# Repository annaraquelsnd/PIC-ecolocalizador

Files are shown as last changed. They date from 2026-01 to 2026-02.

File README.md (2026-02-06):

# Ecolocalizador Tátil para Bicicletas Tandem

Dispositivo de assistência baseado em **feedback tátil** para aumentar a **segurança**, a **confiança** e a **autonomia** de pessoas com deficiência visual na condução de bicicletas tandem.

> Projeto desenvolvido na disciplina **Projeto Integrado de Computação I** para a **Mostra de Computação da UFES** com o professor Jadir E. S. Lucas.

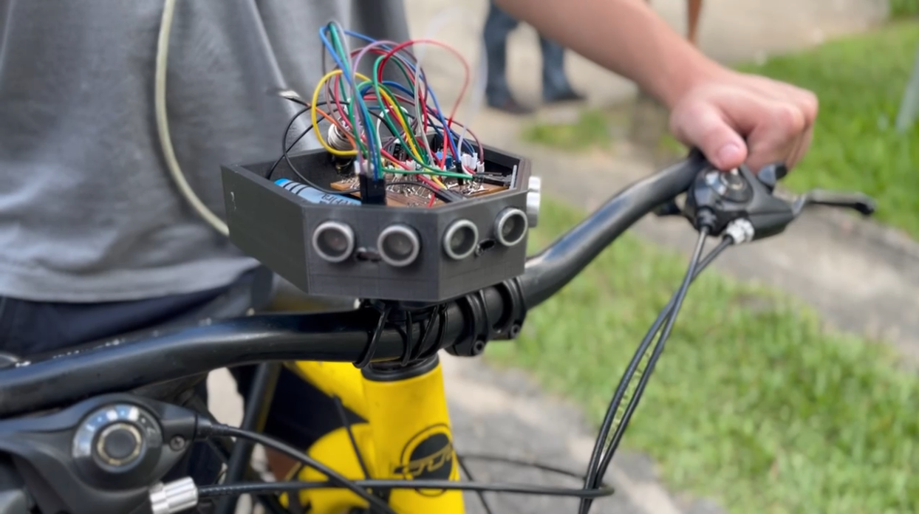
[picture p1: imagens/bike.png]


---

## 📌 Contexto e Motivação

A percepção do ambiente não depende exclusivamente da visão. Casos como o de **Ben Underwood** demonstram que outros sentidos podem ser explorados para navegação espacial.

<p align="center">
  <a href="https://www.youtube.com/watch?v=pt5yYK_4Rjo">
    Ben Underwood
  </a>
</p>
<p align="center">
▶️ Clique na imagem para assistir no YouTube
</p>

Inspirados por essa ideia e por iniciativas como o projeto **Pedal Inclusão**, que utiliza bicicletas tandem para permitir que pessoas com deficiência visual pratiquem o ciclismo, tivemos contato direto com os desafios e possibilidades dessa experiência.

Durante um desses eventos, observamos um participante com deficiência visual conduzir a bicicleta apenas com orientações verbais de sua dupla. A experiência evidenciou o potencial da atividade, mas também deixou claro que a condução exige um alto nível de confiança.

A partir dessa vivência, pensamos em uma **solução técnica** que aumentasse a sensação de segurança e encorajasse mais pessoas com deficiência visual a assumir a condução da bicicleta, tornando a atividade mais inclusiva.

---

## 🎯 Objetivos do Projeto

- Encorajar o ciclista com deficiência visual a conduzir a bicicleta 
- Reduzir a dependência exclusiva de comandos verbais
- Fornecer percepção espacial por meio de feedback tátil
- Tornar a condução mais acessível e o esporte mais inclusivo

---

## 🧠 Visão Geral do Sistema

O sistema é composto por dois módulos principais:

- **Central no guidão da bicicleta**, responsável pela detecção de obstáculos
- **Colete tátil**, responsável por transmitir informações espaciais ao ciclista por meio da vibração

A comunicação entre esses módulos permite que a presença e a direção de obstáculos sejam percebidas.

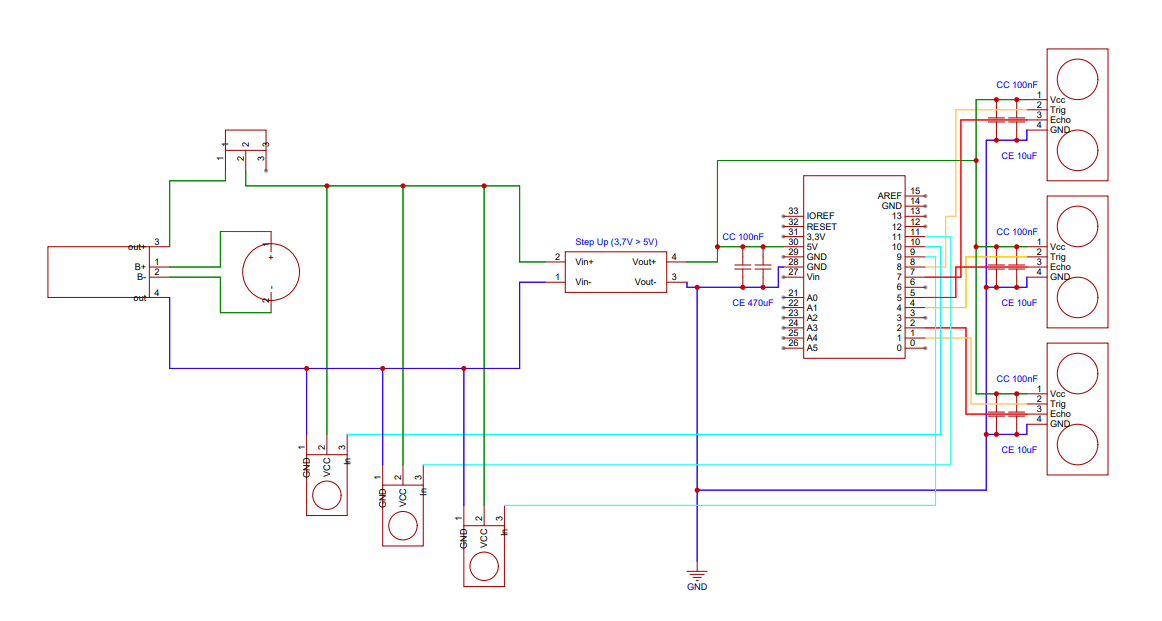
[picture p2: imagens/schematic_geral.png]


---

## 🏗️ Arquitetura do Sistema

### 🔹 Central (Guidão)

A central é responsável pela leitura do ambiente à frente da bicicleta.

#### Componentes principais:
###### Arduino UNO
- Contém o algoritmo que converte a distância medida em intensidade de vibração. Quanto mais perto, maior é a intensidade da vibração.
```c++
...
// Dispara o pulso ultrassônico
digitalWrite(trigPin, LOW);
delayMicroseconds(2);
digitalWrite(trigPin, HIGH);
delayMicroseconds(10);
digitalWrite(trigPin, LOW);

// Lê o retorno
long duracao = pulseIn(echoPin, HIGH);
int distancia = duracao * 0.034 / 2;

// Calcula a Intensidade 
int pwm = 0;

if (distancia == 0 || distancia > DISTANCIA_MAX) {
  pwm = 0; // Desligado
} 
else if (distancia < DISTANCIA_MIN) {
  pwm = 255; // Vibração Máxima
} 
else {
  // Quanto mais perto, mais forte
  pwm = map(distancia, DISTANCIA_MIN, DISTANCIA_MAX, 255, 0);
}

// Aciona o Motor
analogWrite(motorPin, pwm);
...
```

###### 3 sensores ultrassônicos (HC-SR04)
- Dispostos em três faces frontais do chassi angulados em **45º** entre si
Tem um alcance de até 3 metros
- Estão posicionados no guidão, cobrindo aproximadamente **120°** à frente da bicicleta.
<table>
  <tr>
    <td>
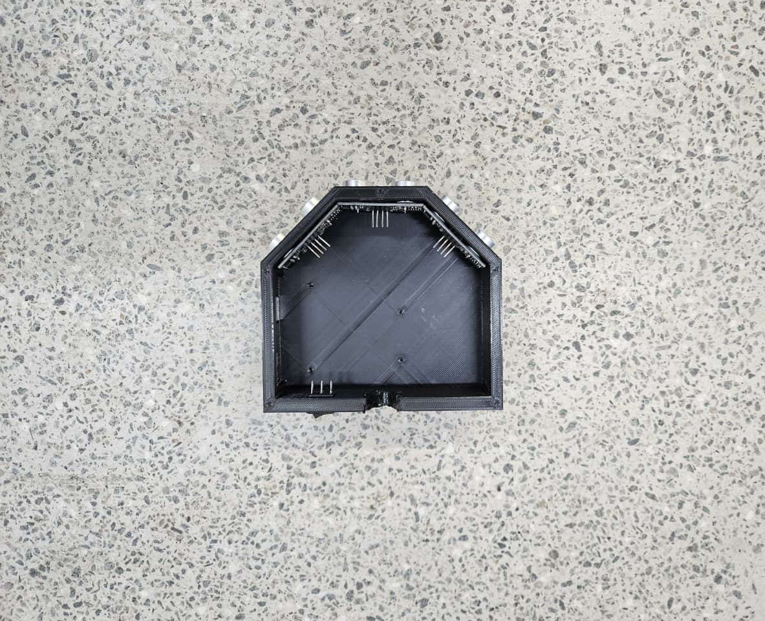
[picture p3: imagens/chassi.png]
      
    </td>
    <td>
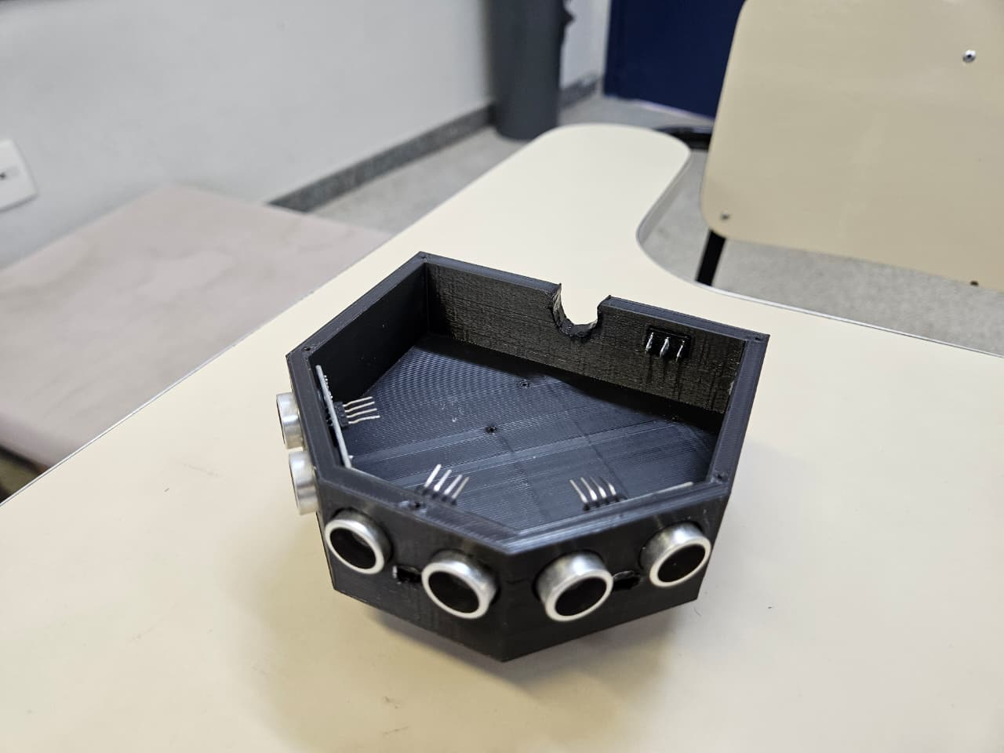
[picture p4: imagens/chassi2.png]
      
  </tr>
</table>

###### Alimentação dedicada
- Bateria 3.7V 18650 recarregável
- Módulo de carregamento TP4056

Esses componentes são centralizados em uma placa PCB:
<table>
  <tr>
    <td>
      
    </td>
    <td>
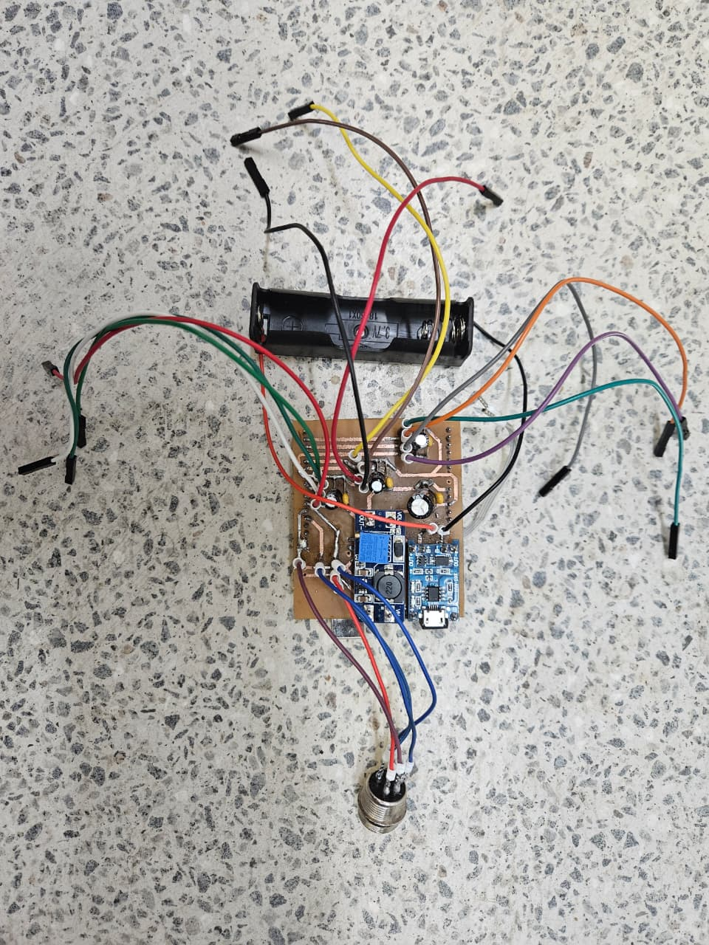
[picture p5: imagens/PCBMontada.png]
      
  </tr>
</table>

---
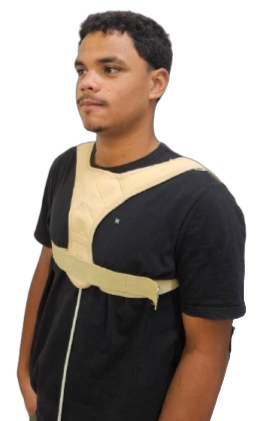
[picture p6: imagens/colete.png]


### 🔹 Colete Tátil

O colete é responsável por fornecer o feedback sensorial ao ciclista.

##### Componentes principais:
- 3 motores de vibração
- PCB
- Estrutura vestível (colete)

##### Os motores estão posicionados:
- Um no centro do peito
- Um em cada ombro

---

## 🔄 Mapeamento Sensor → Vibração

A informação captada pelos sensores é convertida em padrões de vibração, indicando a direção do obstáculo.

| Sensor | Posição no guidão | Motor ativado | Indicação |
|---|---|---|---|
| Sensor esquerdo | Esquerda | Ombro esquerdo | Obstáculo à esquerda |
| Sensor central | Centro | Peito | Obstáculo frontal |
| Sensor direito | Direita | Ombro direito | Obstáculo à direita |

---

## 🧩 Componentes Utilizados

| Componente | Quantidade | Função |
|---|---|---|
| Arduino | 1 | Processamento dos dados |
| Sensor ultrassônico HC-SR04| 3 | Detecção de obstáculos |
| Motor de vibração | 3 | Feedback tátil |
| PCB personalizada | 2 | Integração do sistema |
| Estrutura do colete | 1 | Fixação dos motores |
| Cabos e conectores | Diversos | Interligação |

---

## 🛠️ Processo de Desenvolvimento

#### O desenvolvimento do projeto passou pelas seguintes etapas:

- Levantamento do problema a partir de vivência prática
- Idealização do aparelho
- Levantamento de componentes necessários
- Prototipação inicial
- Projeto e confecção das PCBs
- Modelagem e impressão 3D
- Montagem dos módulos
- Testes funcionais do sistema

<table>
  <tr>
    <td>
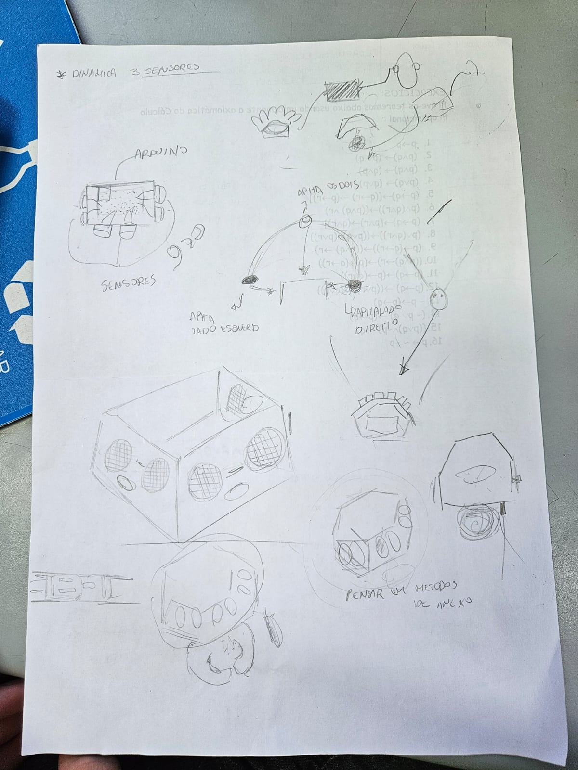
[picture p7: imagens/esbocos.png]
      
    </td>
    <td>
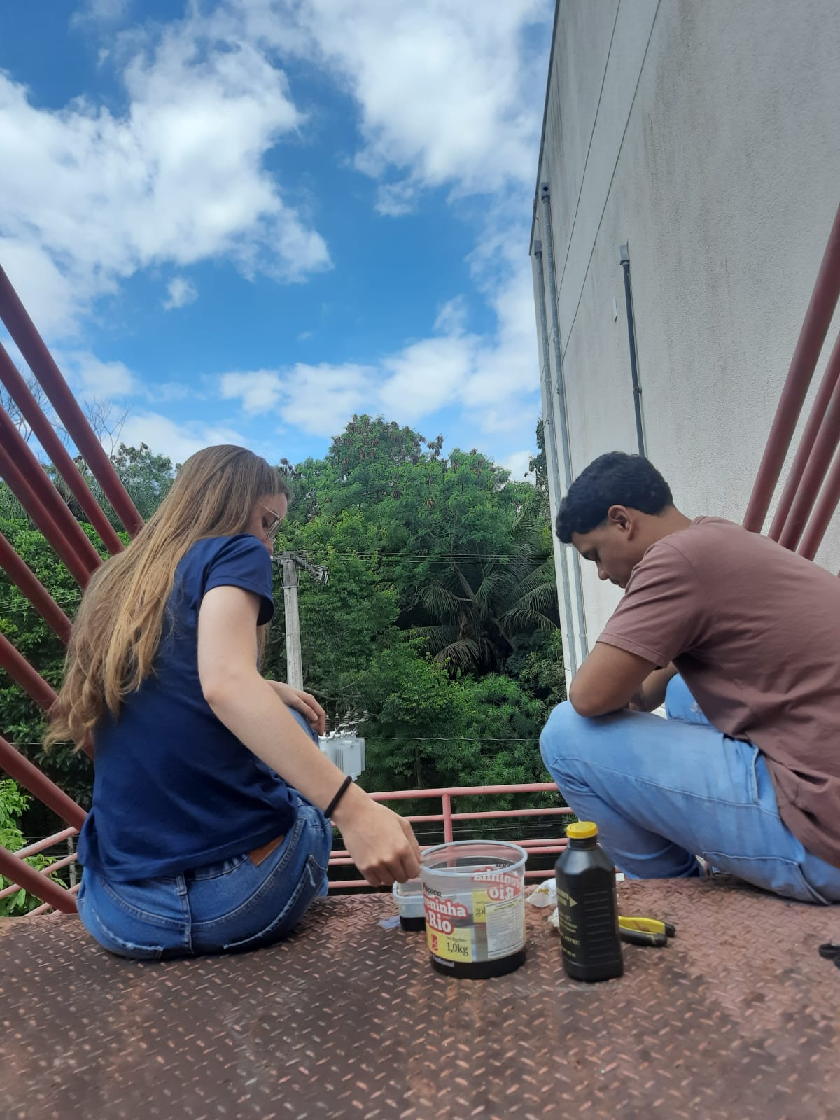
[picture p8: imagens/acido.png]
      
    </td>
  </tr>
</table>
<table>
    <td>
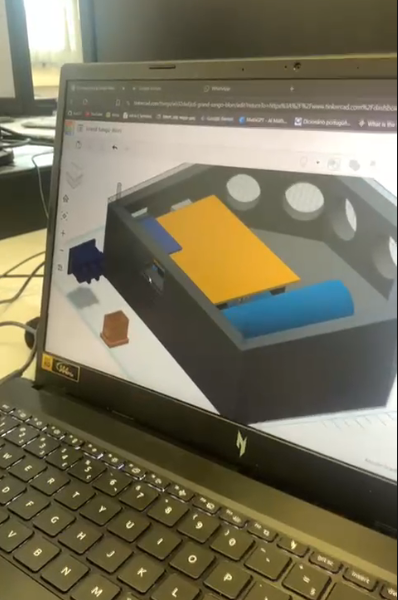
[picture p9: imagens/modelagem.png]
      
    </td>
    <td>
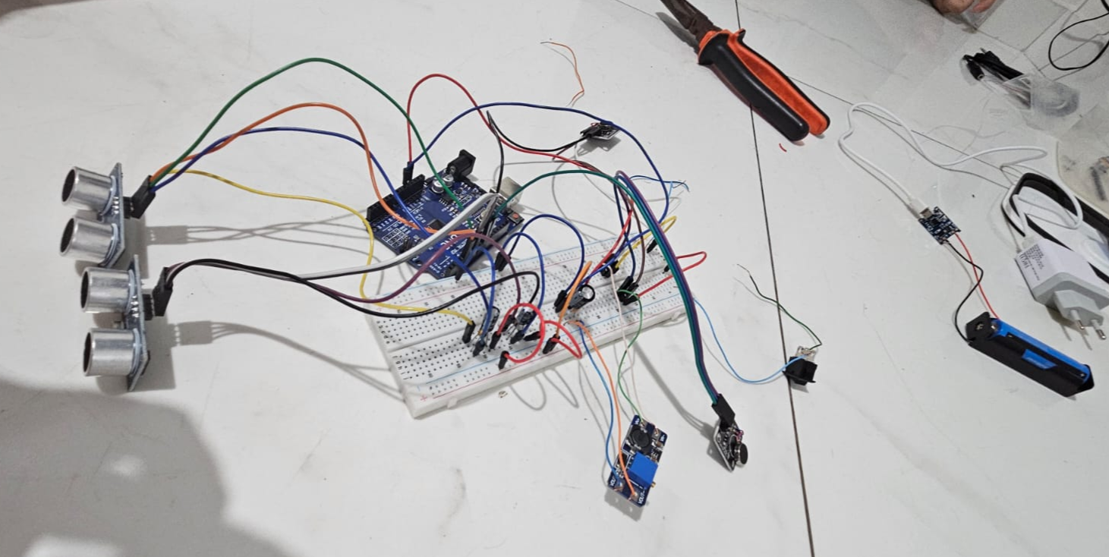
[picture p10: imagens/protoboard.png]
      
    </td>
  </tr>
</table>

---

## 📊 Resultados e Limitações

### Resultados
- Detecção de obstáculos em tempo real
- Feedback tátil claro e direcional
- Integração confortável ao corpo do usuário

### Limitações
- Sistema ainda em fase de protótipo
- Testes limitados a ambientes controlados
- Necessidade de testes com usuários finais

---

## 🔧 Como Reproduzir o Projeto

- Os esquemáticos estão disponíveis em `/schematics`
- Os modelos para impressão em `/models3D`
- Os arquivos de PCB estão disponíveis em `/pcb`
- O código-fonte está disponível na pasta `/src`
- As imagens e diagramas estão em `/imagens`

---

## 👥 Equipe e Agradecimentos

Nossa equipe é composta por: André Luiz Mendes Siqueira de Freitas, Anna Raquel Sandrini, Arthur Manelli, Caetano Zandonade e Daniela Pimentel

## 🤝 Agradecimentos Especiais

| Categoria | Colaboradores |
| :--- | :--- |
| **Projetos & Equipes** | • Pedal Inclusão <br> • Erus (Equipe de Robótica da UFES) |
| **Mentoria Técnica** | • **Profª Mariana Lyra Silveira** (Desenvolvimento da PCB) <br> • **Arthur Ferreira** (Vitória Baja) <br> • **Guido** (PET Engenharia de Computação) |
| **Comunidade & Turma** | • Vinicius Cunha Martins <br> • Vitoria Gomes Fagundes <br> • e aos demais que contribuiram de alguma forma para o projeto. |

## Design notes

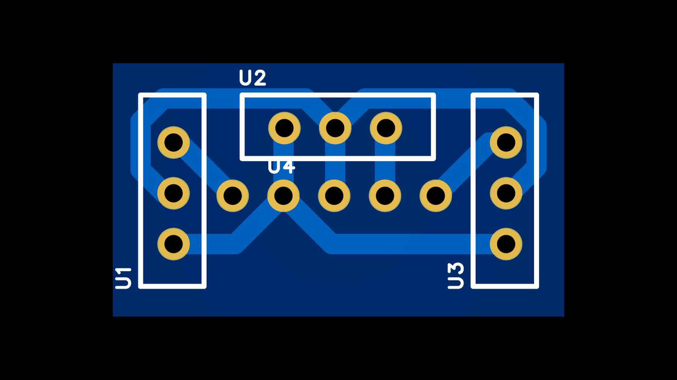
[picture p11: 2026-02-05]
pcb/pcb_colete.png

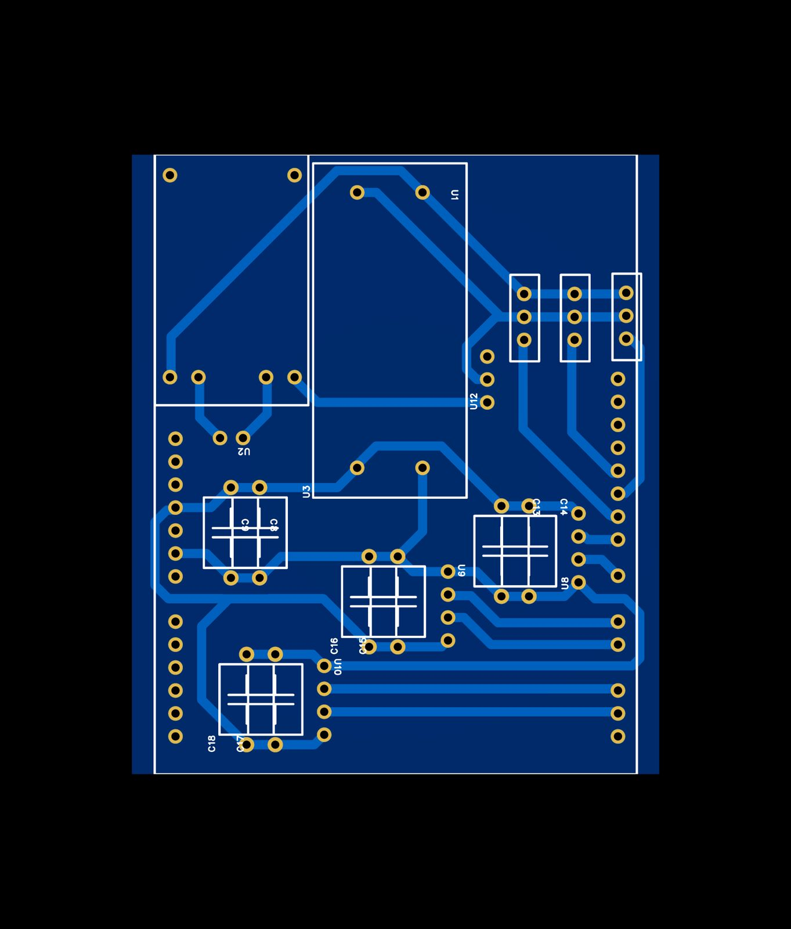
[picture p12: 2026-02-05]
pcb/pcb_central.png

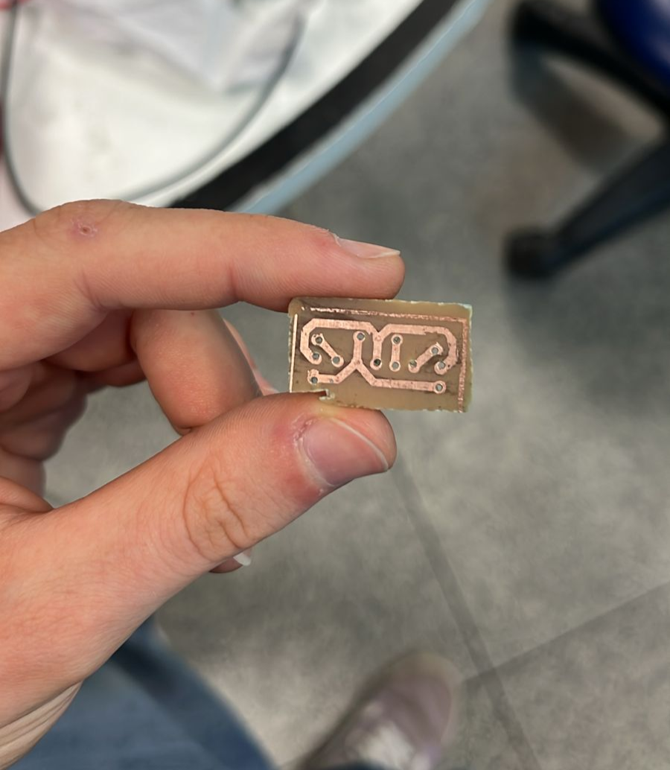
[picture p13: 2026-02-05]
imagens/PCBColete.png

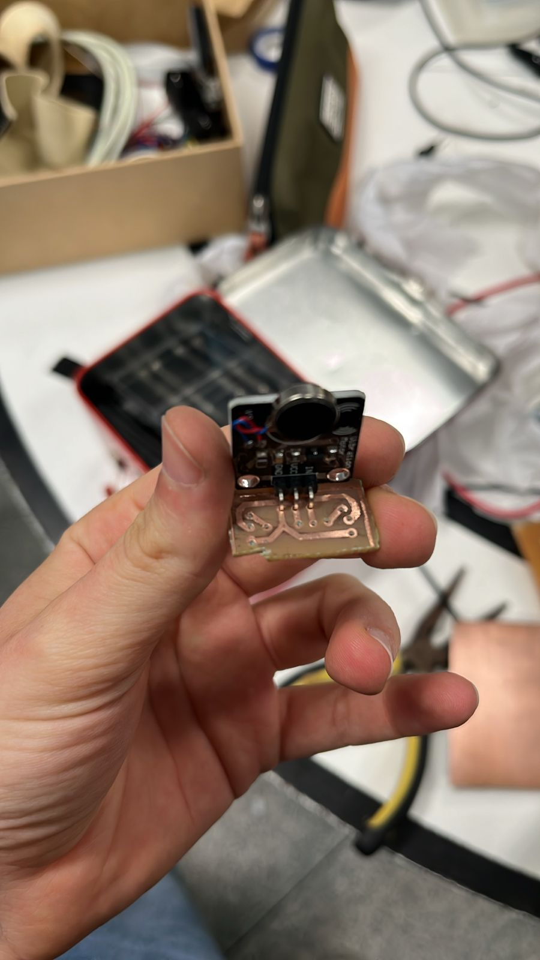
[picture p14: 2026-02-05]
imagens/PCBColeteMont.png

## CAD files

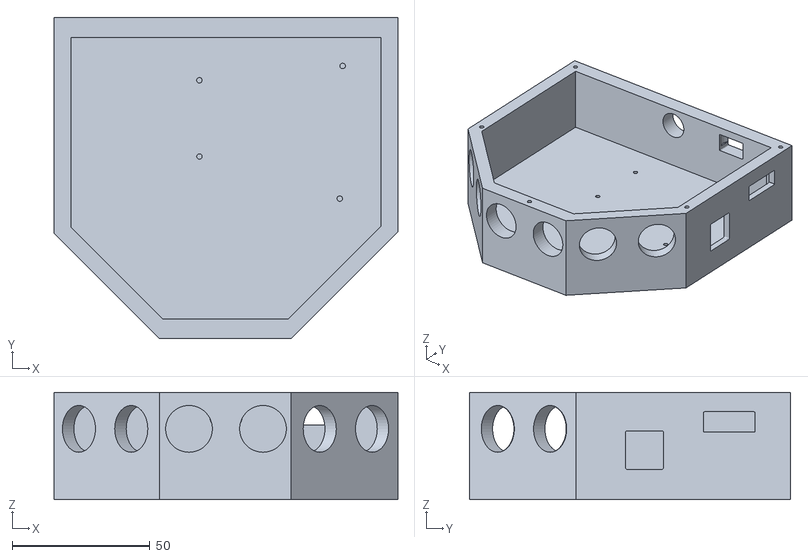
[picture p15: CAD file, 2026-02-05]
models3D/ChassiEco.stl
125.0 x 116.8 x 39.0

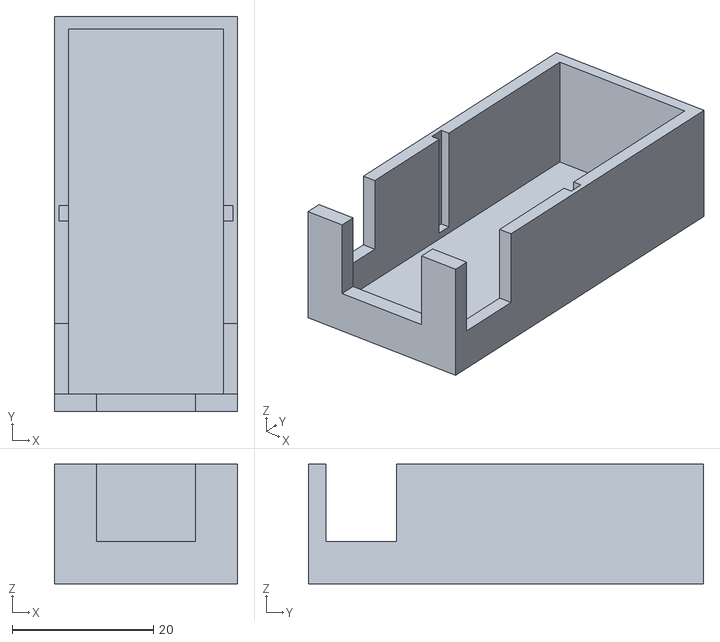
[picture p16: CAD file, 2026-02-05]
models3D/SuporteMotorVibraçãoEco.stl
26.0 x 56.0 x 17.0

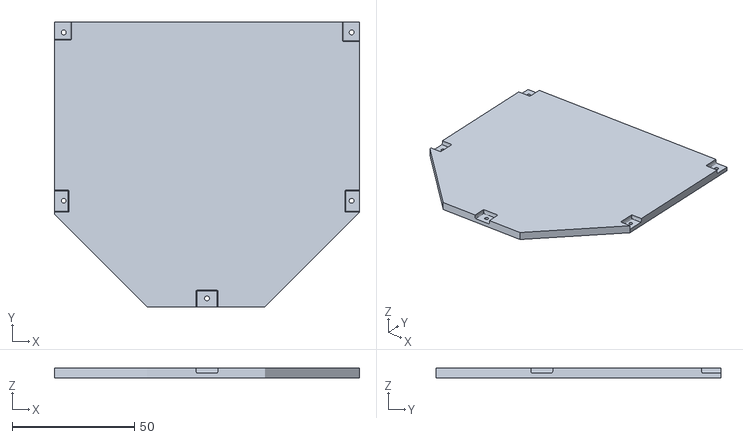
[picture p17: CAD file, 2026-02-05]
models3D/TampaEco_v3.stl
125.0 x 116.8 x 4.00

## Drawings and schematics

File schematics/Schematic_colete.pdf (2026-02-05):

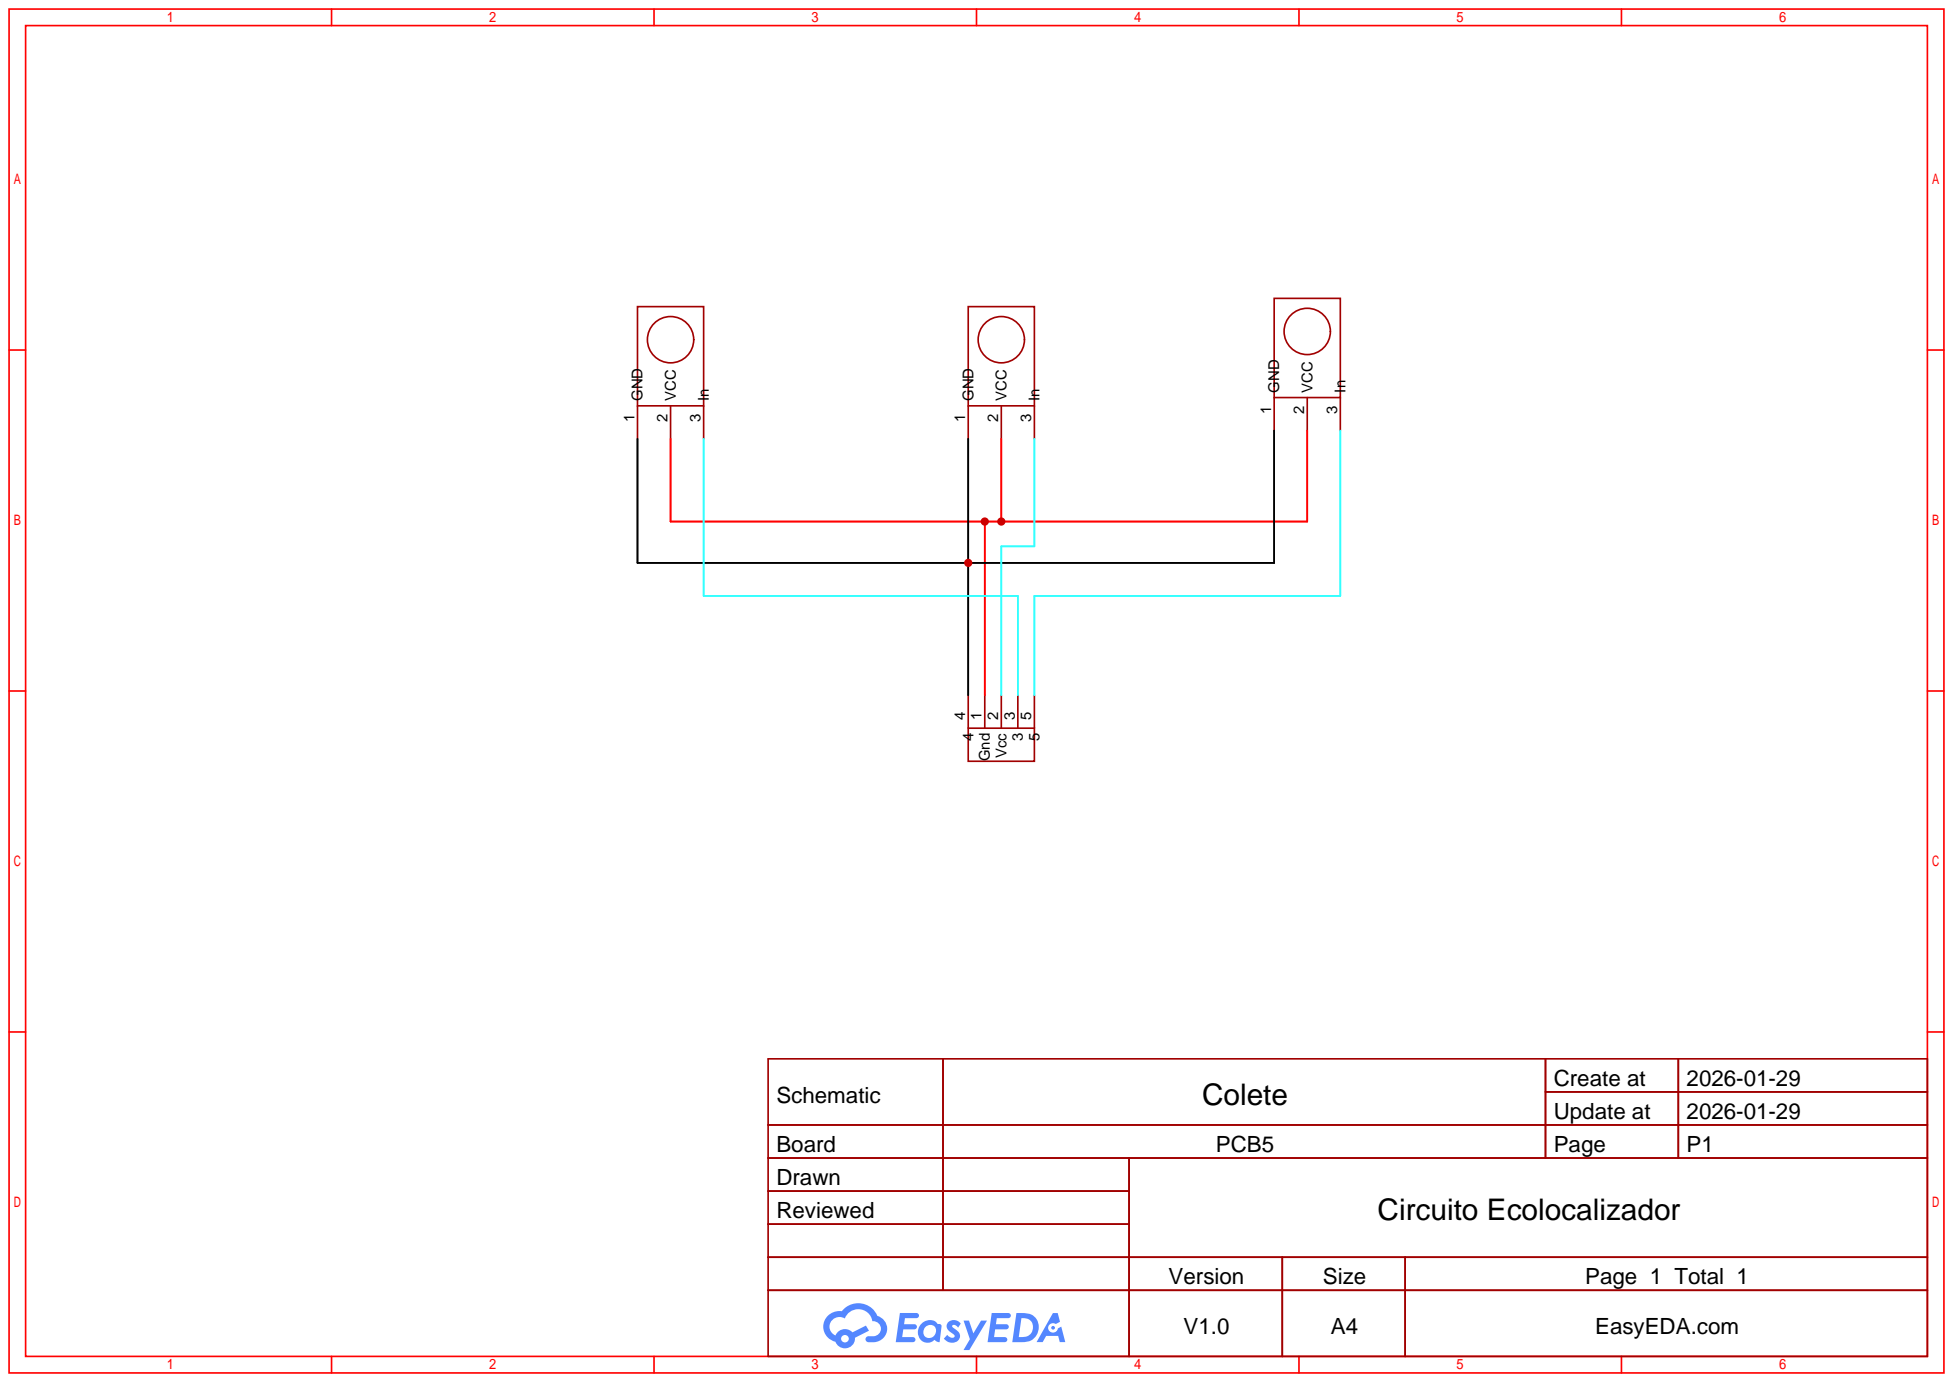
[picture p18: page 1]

Schematic | Colete | Create at | 2026-01-29

Update at | 2026-01-29

Board | PCB5 | Page | P1
Drawn | | Circuito Ecolocalizador
Reviewed

Version | Size | Page 1 Total 1
V1.0 | A4 | EasyEDA.com

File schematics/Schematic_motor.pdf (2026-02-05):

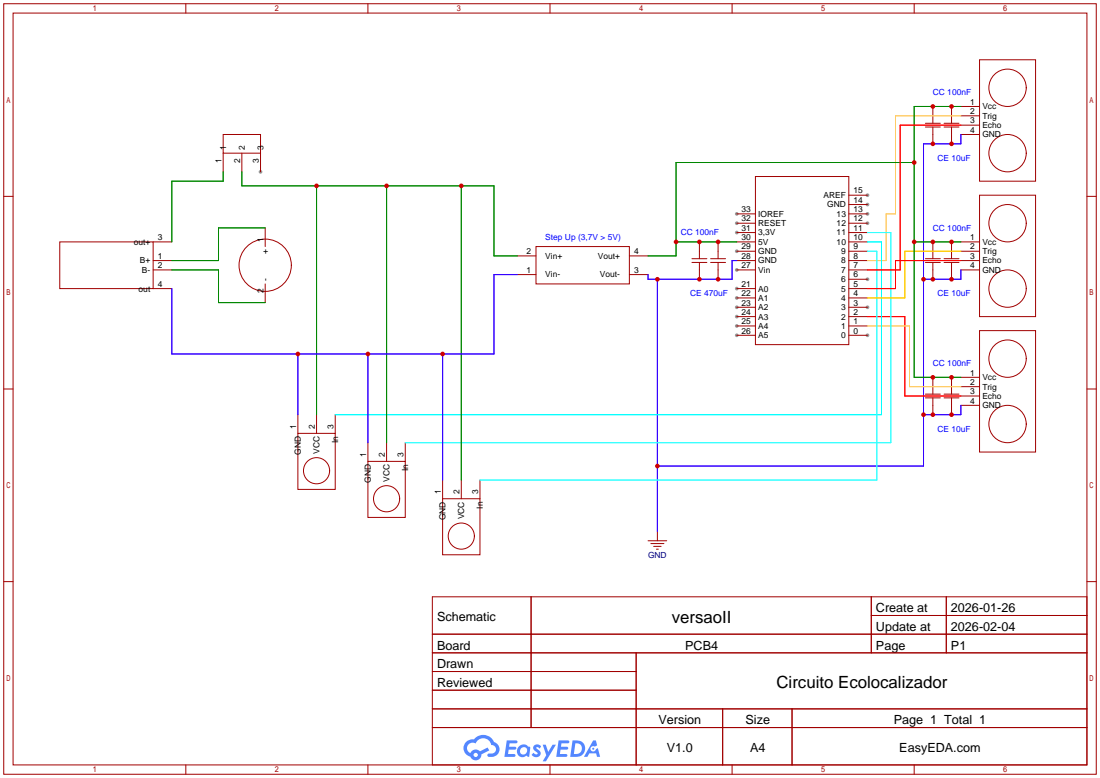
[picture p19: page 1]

Vin 27 GND 28 GND 29 5V 30 3,3V 31 RESET 32 IOREF 33

Schematic | versaoII | Create at | 2026-01-26

Update at | 2026-02-04

Board | PCB4 | Page | P1
Drawn | | Circuito Ecolocalizador
Reviewed

Version | Size | Page 1 Total 1
V1.0 | A4 | EasyEDA.com

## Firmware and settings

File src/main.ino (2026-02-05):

// ============================================================
// DEFINIÇÃO DOS PINOS
// ============================================================

// --- Lado ESQUERDO ---
#define PINO_TRIG_ESQUERDA 8
#define PINO_ECHO_ESQUERDA 7
#define PINO_VIBRACAO_ESQUERDA 11

// --- MEIO (Centro) ---
#define PINO_TRIG_MEIO 4
#define PINO_ECHO_MEIO 5
#define PINO_VIBRACAO_MEIO 10

// --- Lado DIREITO ---
#define PINO_TRIG_DIREITA 12
#define PINO_ECHO_DIREITA 2
#define PINO_VIBRACAO_DIREITA 9

// ============================================================
// CONFIGURAÇÕES GLOBAIS
// ============================================================
<<<<<<<< HEAD:codigoComMotor.ino
const int DISTANCIA_MIN = 100;  // cm (Vibração MÁXIMA)
const int DISTANCIA_MAX = 300; // cm (Vibração INICIA aqui)
========
const int DISTANCIA_MIN = 20;  // cm 
const int DISTANCIA_MAX = 100; // cm 
>>>>>>>> da312fb12d46d45b356fb2eb24cd2caecf81aeea:src/codigoComMotor.ino

void setup() {
  Serial.begin(9600);

  // Configuração Esquerda
  pinMode(PINO_TRIG_ESQUERDA, OUTPUT);
  pinMode(PINO_ECHO_ESQUERDA, INPUT);
  pinMode(PINO_VIBRACAO_ESQUERDA, OUTPUT);

  // Configuração Meio
  pinMode(PINO_TRIG_MEIO, OUTPUT);
  pinMode(PINO_ECHO_MEIO, INPUT);
  pinMode(PINO_VIBRACAO_MEIO, OUTPUT);

  // Configuração Direita
  pinMode(PINO_TRIG_DIREITA, OUTPUT);
  pinMode(PINO_ECHO_DIREITA, INPUT);
  pinMode(PINO_VIBRACAO_DIREITA, OUTPUT);
}

void loop() {
<<<<<<<< HEAD:codigoComMotor.ino
  // Chamamos a função personalizada para cada conjunto
  processarSensor(PINO_TRIG_DIREITA, PINO_ECHO_DIREITA, PINO_VIBRACAO_DIREITA, "Dir");
========

>>>>>>>> da312fb12d46d45b356fb2eb24cd2caecf81aeea:src/codigoComMotor.ino
  processarSensor(PINO_TRIG_ESQUERDA, PINO_ECHO_ESQUERDA, PINO_VIBRACAO_ESQUERDA, "Esq");
  processarSensor(PINO_TRIG_MEIO, PINO_ECHO_MEIO, PINO_VIBRACAO_MEIO, "Meio");
  
  // Pequeno delay para não sobrecarregar processamento e dar tempo aos ecos
  delay(10); 
}


void processarSensor(int trigPin, int echoPin, int motorPin, String nome) {
  
  // Dispara o pulso ultrassônico
  digitalWrite(trigPin, LOW);
  delayMicroseconds(2);
  digitalWrite(trigPin, HIGH);
  delayMicroseconds(10);
  digitalWrite(trigPin, LOW);

  // Lê o retorno
  long duracao = pulseIn(echoPin, HIGH);
  int distancia = duracao * 0.034 / 2;

  // Calcula a Intensidade 
  int pwm = 0;

  if (distancia == 0 || distancia > DISTANCIA_MAX) {
    pwm = 0; // Desligado
  } 
  else if (distancia < DISTANCIA_MIN) {
    pwm = 255; // Vibração Máxima
  } 
  else {
    // Quanto mais perto, mais forte
    pwm = map(distancia, DISTANCIA_MIN, DISTANCIA_MAX, 255, 0);
  }

  // Aciona o Motor
  analogWrite(motorPin, pwm);

<<<<<<<< HEAD:codigoComMotor.ino
  // 5. Debug (Opcional - para ver no Monitor Serial)
  // Descomente as linhas abaixo para testar
  
  // if (nome == "Esq"){
  //   Serial.print(nome);
  //   Serial.print(": ");
  //   Serial.print(distancia);
  //   Serial.print("cm -> PWM: ");
  //   Serial.println(pwm);
  //   delay(500);
  // }
========
  // Debug
  // Serial.print(nome);
  // Serial.print(": ");
  // Serial.print(distancia);
  // Serial.print("cm -> PWM: ");
  // Serial.println(pwm);
>>>>>>>> da312fb12d46d45b356fb2eb24cd2caecf81aeea:src/codigoComMotor.ino
  
}

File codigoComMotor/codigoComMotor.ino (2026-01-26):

// ============================================================
// DEFINIÇÃO DOS PINOS
// ============================================================

// --- Lado ESQUERDO ---
#define PINO_TRIG_ESQUERDA 7
#define PINO_ECHO_ESQUERDA 6
#define PINO_VIBRACAO_ESQUERDA 9 

// --- MEIO (Centro) ---
#define PINO_TRIG_MEIO 5
#define PINO_ECHO_MEIO 4
#define PINO_VIBRACAO_MEIO 10    

// --- Lado DIREITO ---
#define PINO_TRIG_DIREITA 3
#define PINO_ECHO_DIREITA 2
#define PINO_VIBRACAO_DIREITA 11   

// ============================================================
// CONFIGURAÇÕES GLOBAIS
// ============================================================
const int DISTANCIA_MIN = 20;  // cm (Vibração MÁXIMA)
const int DISTANCIA_MAX = 100; // cm (Vibração INICIA aqui)

void setup() {
  Serial.begin(9600);

  // Configuração Esquerda
  pinMode(PINO_TRIG_ESQUERDA, OUTPUT);
  pinMode(PINO_ECHO_ESQUERDA, INPUT);
  pinMode(PINO_VIBRACAO_ESQUERDA, OUTPUT);

  // Configuração Meio
  pinMode(PINO_TRIG_MEIO, OUTPUT);
  pinMode(PINO_ECHO_MEIO, INPUT);
  pinMode(PINO_VIBRACAO_MEIO, OUTPUT);

  // Configuração Direita
  pinMode(PINO_TRIG_DIREITA, OUTPUT);
  pinMode(PINO_ECHO_DIREITA, INPUT);
  pinMode(PINO_VIBRACAO_DIREITA, OUTPUT);
}

void loop() {
  // Chamamos a função personalizada para cada conjunto
  processarSensor(PINO_TRIG_ESQUERDA, PINO_ECHO_ESQUERDA, PINO_VIBRACAO_ESQUERDA, "Esq");
  processarSensor(PINO_TRIG_MEIO, PINO_ECHO_MEIO, PINO_VIBRACAO_MEIO, "Meio");
  processarSensor(PINO_TRIG_DIREITA, PINO_ECHO_DIREITA, PINO_VIBRACAO_DIREITA, "Dir");

  // Pequeno delay para não sobrecarregar processamento e dar tempo aos ecos
  delay(10); 
}

// ============================================================
// FUNÇÃO AUXILIAR: Faz tudo (Lê sensor -> Calcula -> Vibra)
// ============================================================
void processarSensor(int trigPin, int echoPin, int motorPin, String nome) {
  
  // 1. Dispara o pulso ultrassônico
  digitalWrite(trigPin, LOW);
  delayMicroseconds(2);
  digitalWrite(trigPin, HIGH);
  delayMicroseconds(10);
  digitalWrite(trigPin, LOW);

  // 2. Lê o retorno
  long duracao = pulseIn(echoPin, HIGH);
  int distancia = duracao * 0.034 / 2;

  // 3. Calcula a Intensidade (Lógica Inversa)
  int pwm = 0;

  // Se a distância for 0, geralmente é erro de leitura ou fora de alcance.
  // Vamos tratar como "longe" para evitar vibração falsa.
  if (distancia == 0 || distancia > DISTANCIA_MAX) {
    pwm = 0; // Desligado
  } 
  else if (distancia < DISTANCIA_MIN) {
    pwm = 255; // Vibração Máxima
  } 
  else {
    // Mapeia: Quanto mais perto, mais forte
    pwm = map(distancia, DISTANCIA_MIN, DISTANCIA_MAX, 255, 0);
  }

  // 4. Aciona o Motor
  analogWrite(motorPin, pwm);

  // 5. Debug (Opcional - para ver no Monitor Serial)
  // Descomente as linhas abaixo para testar
  
  // Serial.print(nome);
  // Serial.print(": ");
  // Serial.print(distancia);
  // Serial.print("cm -> PWM: ");
  // Serial.println(pwm);
  
}

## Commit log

2025-12-04 first commit algoritmo de som
2025-12-18 Definindo panning e iniciando conexao I2C com digital pot
2026-01-26 Código para versão com motor
2026-02-04 Atualizando README
    [ChassiEco.stl, SuporteMotorVibraçãoEco.stl, TampaEco_v3.stl]
2026-02-05 aiaiai
    adição d de novas pessoas para agredecimento
